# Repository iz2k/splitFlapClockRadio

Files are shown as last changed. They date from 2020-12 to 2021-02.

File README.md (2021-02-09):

# splitFlapClockRadio

---
**Table of contents**
- [DIY brief](#diy-brief)
- [3D design](#3d-design)
  * [SplitFlapDigit](#splitflapdigit)
  * [Cover](#cover)
- [Electronics hardware](#electronics-hardware)
- [SplitFlap controller firmware](#splitflap-controller-firmware)
- [Main Control Software](#main-control-software)
  * [Python backend](#python-backend)
  * [Angular Frontend](#angular-frontend)
    + [Dashboard](#dashboard)
    + [Clock](#clock)
    + [Radio](#radio)
    + [Spotify](#spotify)
    + [Sensors](#sensors)
    + [Weather](#weather)
    + [Historic](#historic)
---

The splitFlapClockRadio is an old stylish, classic alarm clock with up to date features, such as automatic time adjustment, weather forecast, air quality sensors, FM radio or Spotify playback. This is an updated version of the [Flip-Clock](https://github.com/iz2k/flip-clock), with slight modifications on the split-flap mechanics and integrated electronics. This device has been designed for DIY hobbists and can be manufactured for 100$ BOM.

| Outside | Inside |
|---|---|
||IMG_20210208_174947 - copia|

The splitFlapClockRadio features the following characteristics:
- Local time and weather on 3D printed split-flaps.
- 2W I2S Class-D Stereo Amplifier
- FM radio
- Spotify
- Air Quality measurements (eCO2 and TVOC)
- 32 x RGB LED array light
- Spoken weather forecasts (openWeatherMap + TTS)
- Volume and Media control rotary encoder wheels
- Powered by a Raspberry Pi 3A+

The project is divided in four main sections: 3D design, electronics hardware design, split-flap controller MCU firmware (C++) and main software (Python backend + Angular frontend).

## DIY brief
- [ ] Print 3D parts
- [ ] Manufacture PCB (<20$ with [JLCPB](https://jlcpcb.com/))
- [ ] Populate PCB with [Hot Air Gun](https://satkit.com/es/aoyue-int738-sistema-de-reparacion-profesional-soldador-60w)
- [ ] Flash MSP430 MCU
- [ ] Set-up fresh RaspberryPiOS Lite SD card ([tutorial](https://www.raspberrypi.org/software/))
- [ ] Install splitFlapClockRadio barebone:
`wget -O - https://raw.githubusercontent.com/iz2k/splitFlapClockRadio/master/sw/shInstall/barebone.sh | bash `
- [ ] Reboot and enjoy!

## 3D design

### SplitFlapDigit

Each split-flap digit consists of a support structure with two bearings. The axle is placed inside the bearings holding two flap holders. All the flaps are mounted within those holders. The movement of the digit is achieved with a stepper motor and two gears. A reflective IR sensor is used to detect falling flaps, and a hall sensor to synchronize the absolute position of the drum.


In order to get numbers and weather icons painted into the flaps, custom stencils have been designed and printed. The stencil design is avaiable at [iz2k/splitFlap-stencil](https://github.com/iz2k/splitFlap-stencil) repository.
stencil

### Cover
The cover consist on 3 main parts and 2 control wheels:
- Floor
- Top cover
- Frontal
- Volume wheel
- Media wheel


| Front Right |
|--------|
||

| Front Left |
|--------|
||

| Rear |
|--------|
||

## Electronics hardware
The electronics hardware integrates the following components:
- AC/DC converter
- MSP430FR2476 MCU as splitFlap controller
- 3 x ULN2003 stepper driver
- 3 x OPB733 reflective IR sensor
- 3 x DRV5055 hall sensor
- 1 x Si4731 FM radio tuner
- 2 x MAX98357 I2S audio amplifier (stereo)
- 32 x WS2812-2020 RGB LED
- Air Quality sensors: 1 x BME680 + 1 x SGP30/SGP40

splitFlapClockRadio_3D_Image
## SplitFlap controller firmware

The firmware runs on a MSP430 MCU and controls the driver of the three integrated stepper motors. The firmware keeps track of the falling flaps based on the reflected IR detector and synchronizes every cycle based on a hall efect sensor. The MCU can be commanded through I2C bus using SMBUS commands.

## Main Control Software
Tha main functionality of the clock is controlled by the Python backend. It controlls all the peripherals and makes the system work upon user interface with the rotary encoders or the orders triggered through the frontend.

The frontend is an Angular application that allows checking and modifying the current status and configuration of the system. It is accesible withtin the WLAN through a web browser ponting to the configured hostname of the Raspberry Pi.

### Python backend
The backend is divided in different packages to control specific peripherals of the systems:
- Alarm: controls activation of the configured alarms.
- Audio: controls the alsa sound system to trigger sounds and control volume.
- Clock: controls the split-flap controller via SMBUS.
- Config: controls the configuration file.
- DB: interfaces a MariaDB database to log periodic weather and Air Quality data.
- OsInfo: passes current OS infor to the frontend.
- RadioTuner: controls the integrated Si4731 FM tuner IC
- RgbStrip: controls the WS2812 RGB LED strip.
- SpotifyPlayer: activates raspotify device and controls the playback of spotify via spotify-cli.
- UserInterface: controls the Volume and Media rotary encoders.
- WeatherStation: gets weather information through OpenWeatherMap API and controls Air Quality sensors.
- WebServer: integrated Flask webserver to connect with the frontend via REST requests and/or websockets.

The backend is by default installed as a system service (autostart enabled), but can be stopped and launched manually to check its output.
``` bash
sudo service splitFlapClockRadioBackend stop
sudo splitFlapClockRadioBackend
```


### Angular Frontend
The frontend is also divided in different modules:
#### Dashboard
- Quik view of current status


#### Clock
- Current time and alarm list

- SplitFlap calibration

- Alarm configuration


#### Radio
- FM radio tuner control and stored station list.


#### Spotify
- Playback control and stored media item list

- Authentication

- Music search


#### Sensors
- Air Quality sensor data and calibration.


#### Weather
- Weather data, location configuration and API keys.


#### Historic
- Logged weather and Air Quality data


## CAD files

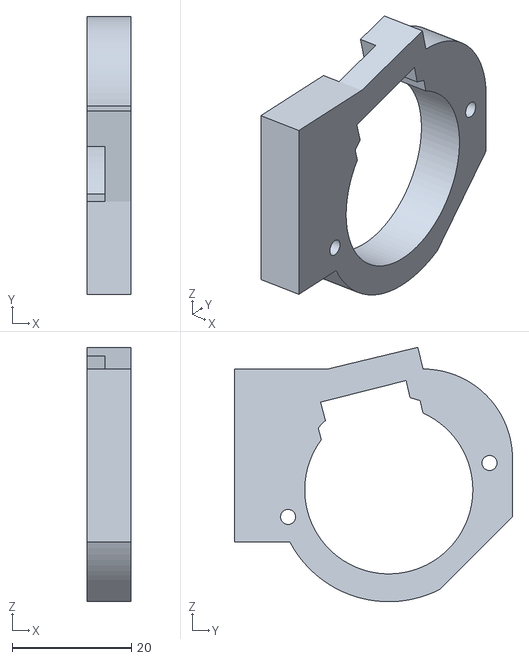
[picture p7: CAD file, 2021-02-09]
3d/outputs/support-stepper-R.stl
7.40 x 46.6 x 42.7

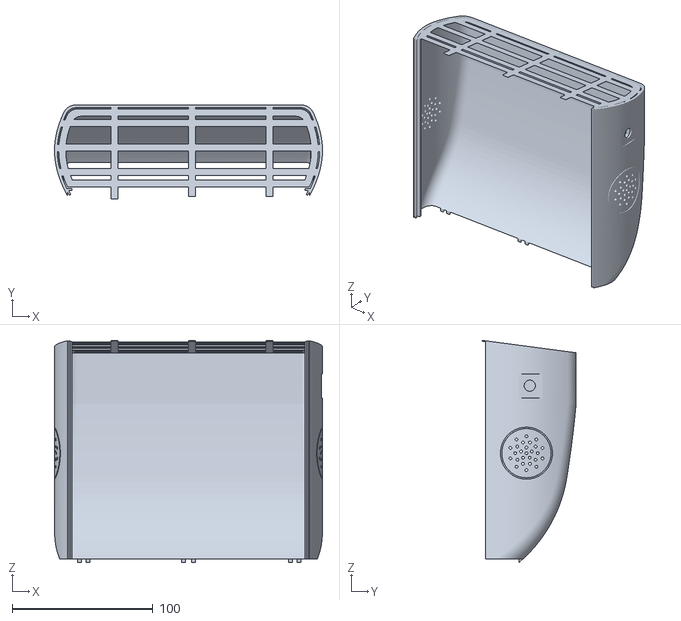
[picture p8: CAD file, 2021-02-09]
3d/outputs/cover.stl
190.6 x 67.1 x 158.1

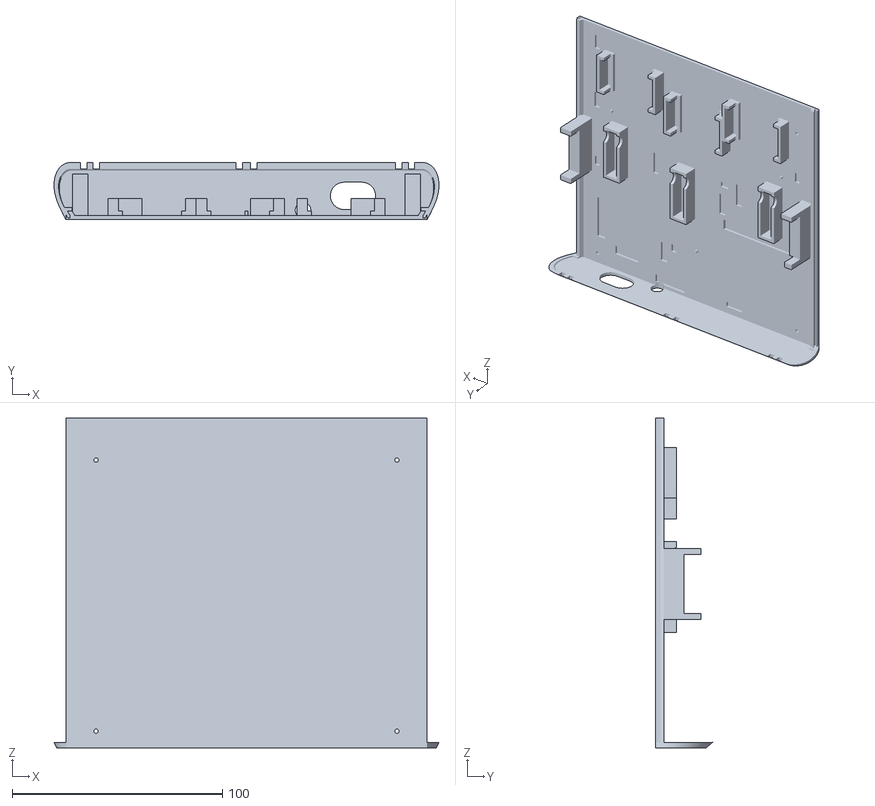
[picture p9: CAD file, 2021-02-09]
3d/outputs/floor.stl
183.2 x 27.1 x 157.0

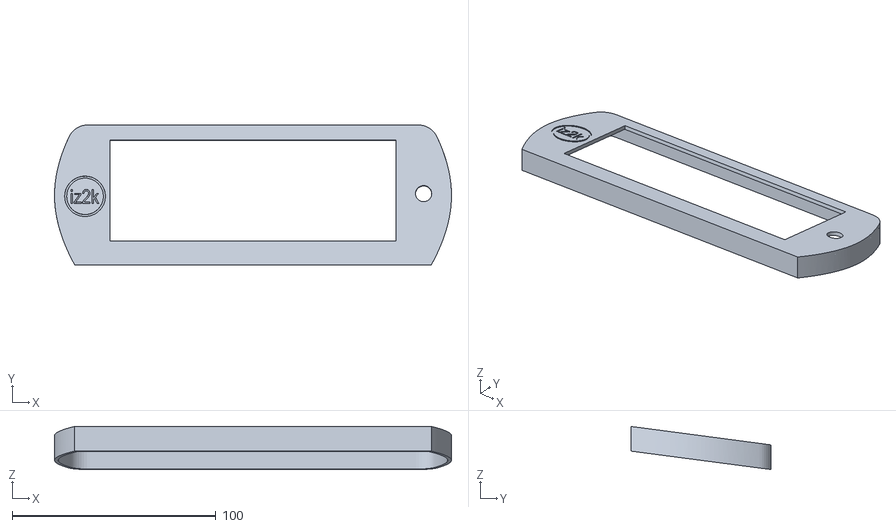
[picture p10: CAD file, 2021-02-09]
3d/outputs/Frontal.stl
194.6 x 68.6 x 21.1

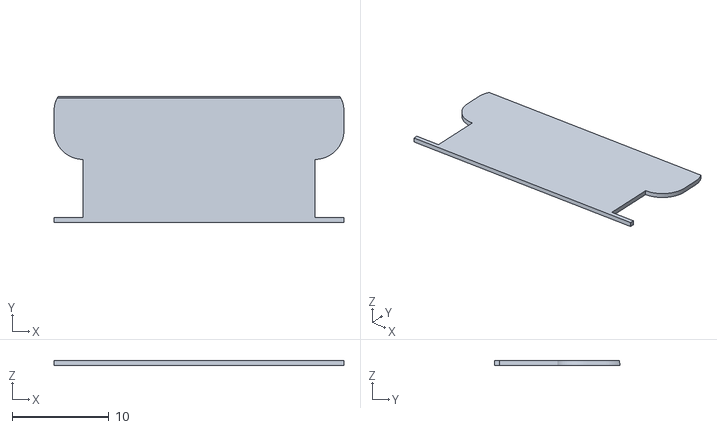
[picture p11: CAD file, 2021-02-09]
3d/outputs/flap-60.stl
30.0 x 13.0 x 0.5

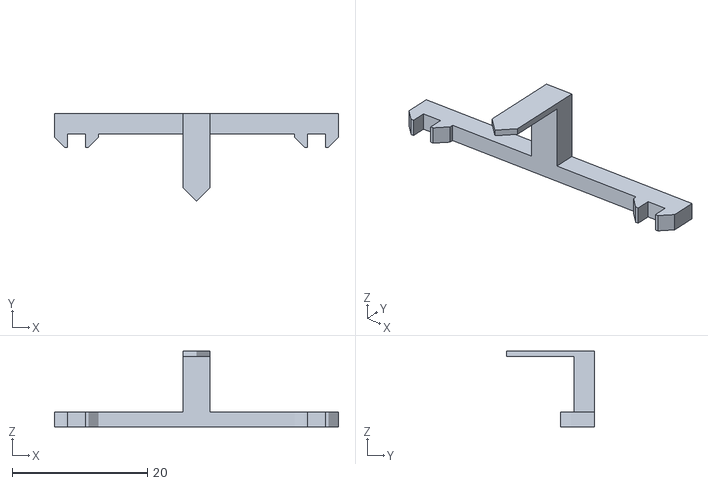
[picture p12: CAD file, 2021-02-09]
3d/outputs/support-drum-bridge-60.stl
42.0 x 13.0 x 11.2

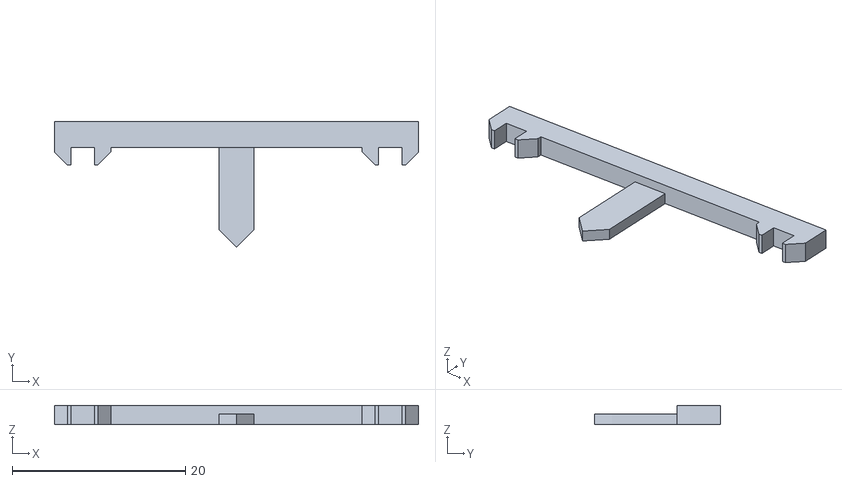
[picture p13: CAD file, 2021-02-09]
3d/outputs/support-drum-bridge-24.stl
42.0 x 14.5 x 2.20

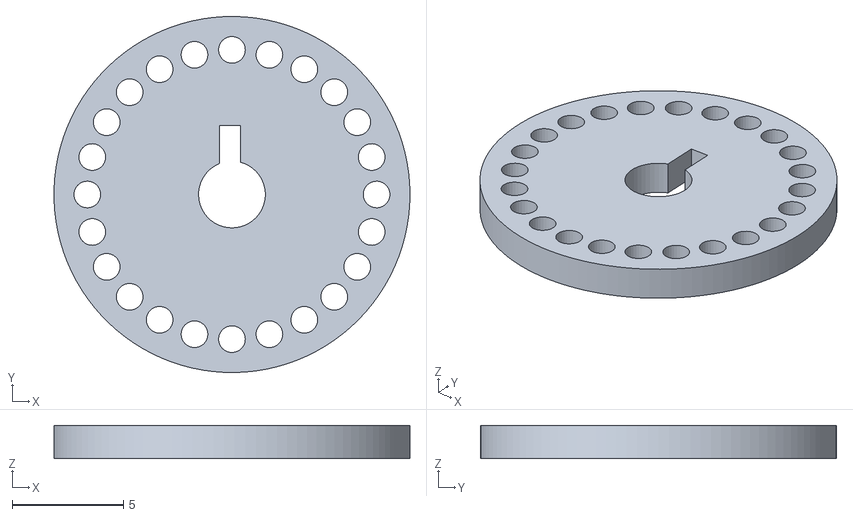
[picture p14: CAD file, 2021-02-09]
3d/outputs/flap-holder-24.stl
16.0 x 16.0 x 1.50

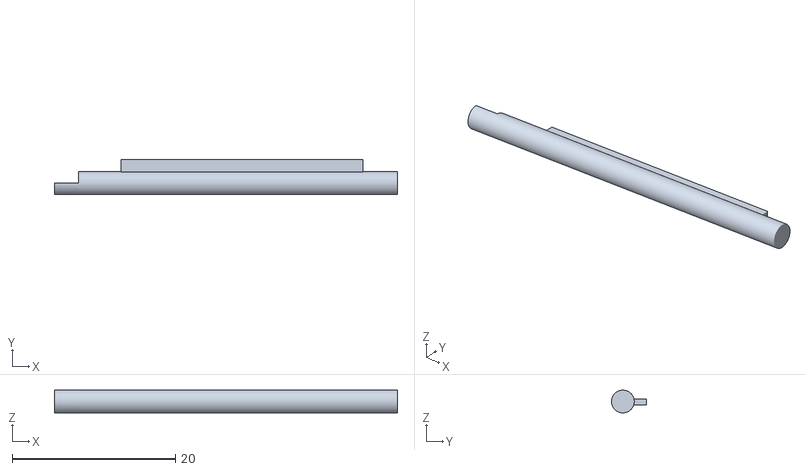
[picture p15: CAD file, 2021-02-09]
3d/outputs/axle.stl
42.0 x 4.30 x 2.80

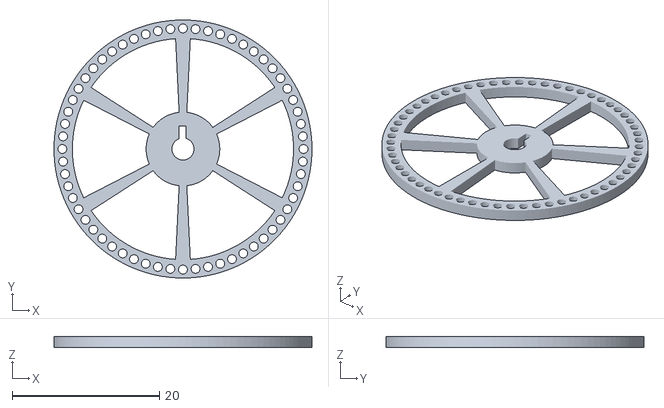
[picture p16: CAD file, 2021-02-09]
3d/outputs/flap-holder-60.stl
35.0 x 35.0 x 1.50

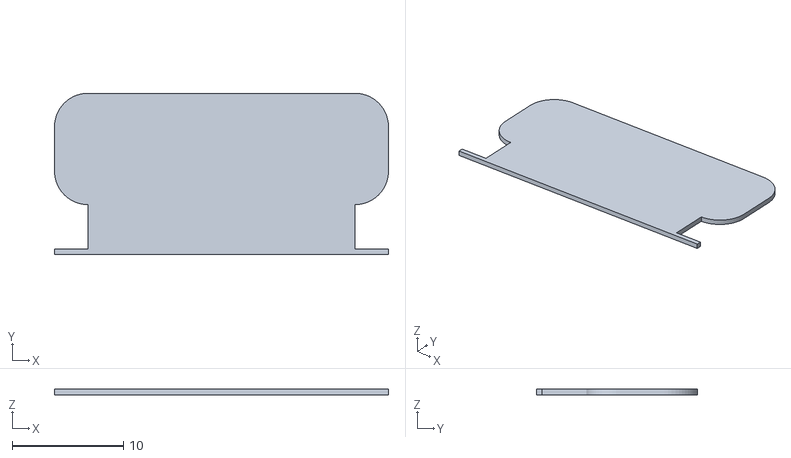
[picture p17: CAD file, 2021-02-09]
3d/outputs/flap-24.stl
30.0 x 14.5 x 0.5

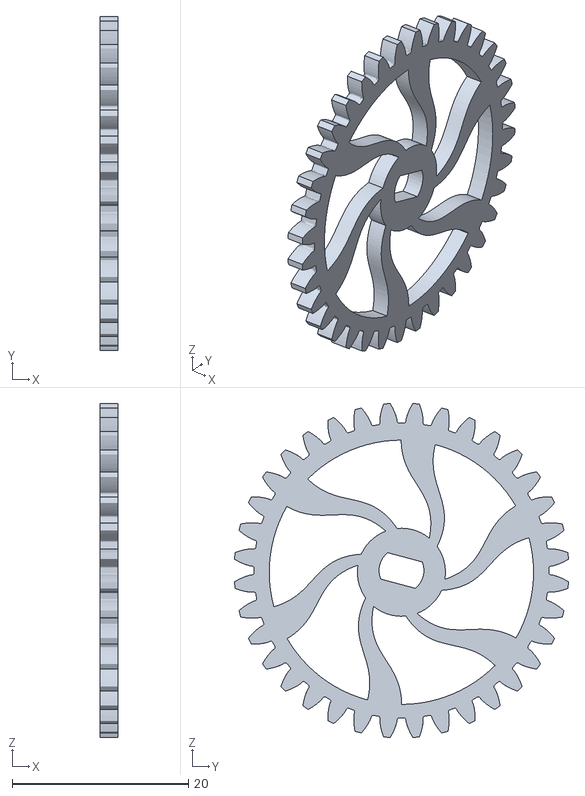
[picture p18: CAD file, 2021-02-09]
3d/outputs/gear-stepper.stl
2.00 x 37.9 x 37.9

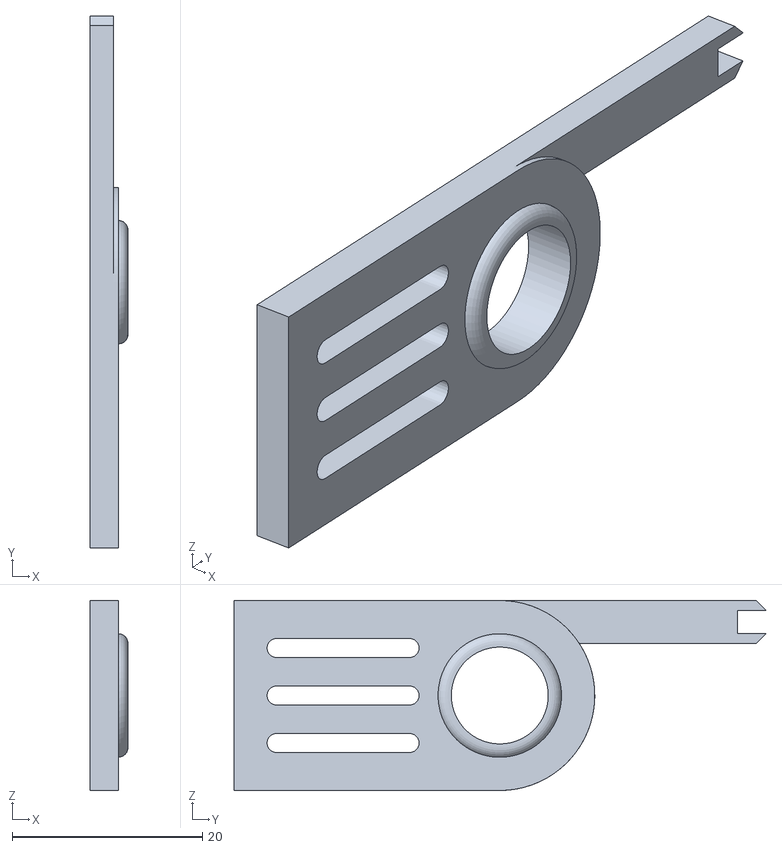
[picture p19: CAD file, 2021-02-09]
3d/outputs/support-drum-L.stl
4.00 x 56.0 x 20.0

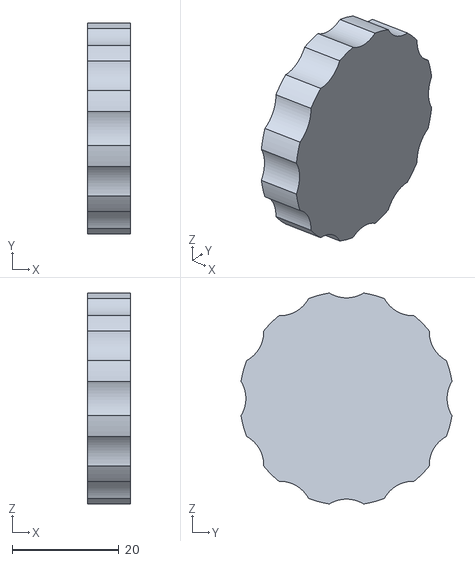
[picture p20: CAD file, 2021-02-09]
3d/outputs/ui_Volume_Wheel.stl
8.00 x 39.5 x 39.5

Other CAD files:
3d/outputs/support-stepper-L.stl
3d/outputs/ui_Control_Wheel.stl
3d/outputs/support-drum-R.stl
3d/outputs/footer.stl
3d/outputs/gear-axle.stl

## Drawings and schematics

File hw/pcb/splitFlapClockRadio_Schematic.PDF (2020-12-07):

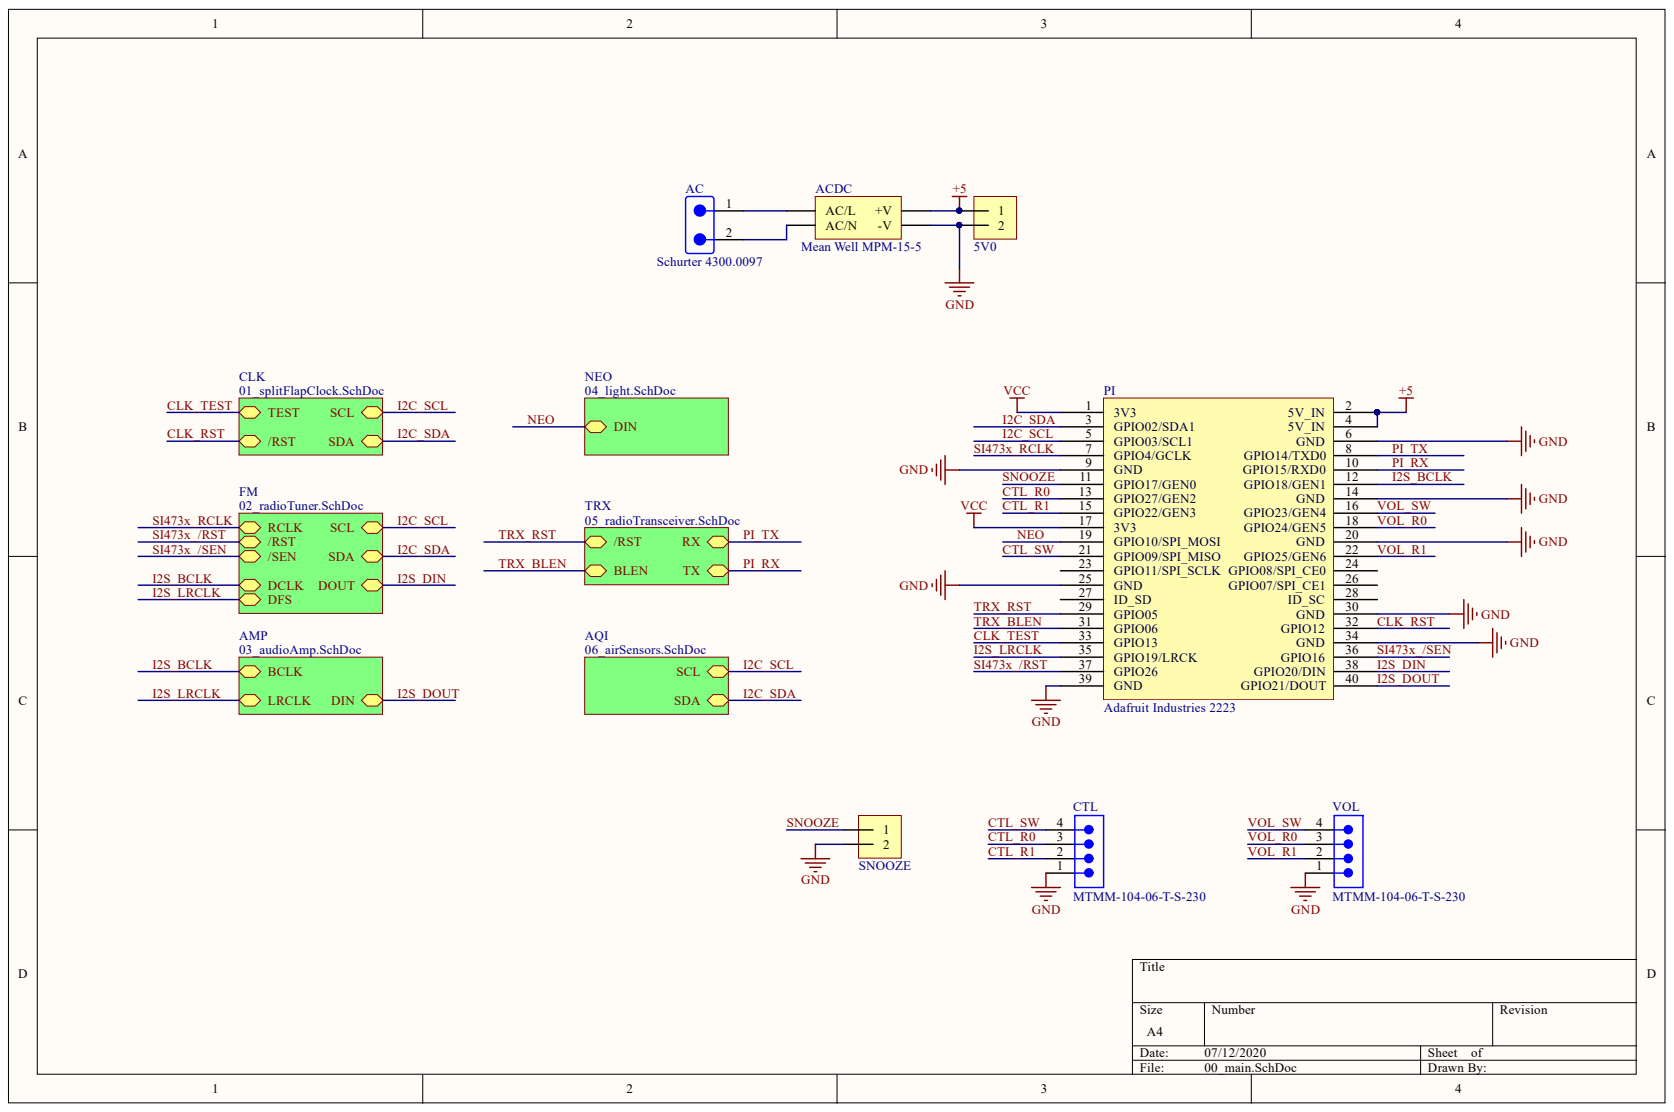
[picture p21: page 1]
Date:; Sheet of; File:; 00_main.SchDoc; Drawn By:; 4 GPIO02/SDA1 3; GPIO03/SCL1 5; GND; GPIO4/GCLK 7; GPIO14/TXD0; GND 9; GPIO15/RXD0; GPIO17/GEN0 11 GPIO27/GEN2 13 GPIO22/GEN3 15 3V3 17 GPIO10/SPI_MOSI 19 GPIO09/SPI_MISO 21 GPIO11/SPI_SCLK 23 GND 25; GPIO05 29 GPIO06 31 GPIO13 33 GPIO19/LRCK 35 GPIO26 37; GND 39; GPIO21/DOUT; 40 GPIO20/DIN; 38 GPIO16; 36 GND; 34 GPIO12; 32 GND; GPIO07/SPI_CE1; 26 GPIO08/SPI_CE0; 24 GPIO25/GEN6; 22 GND; 20 GPIO24/GEN5; 18 GPIO23/GEN4; 16 GND; 14 GPIO18/GEN1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

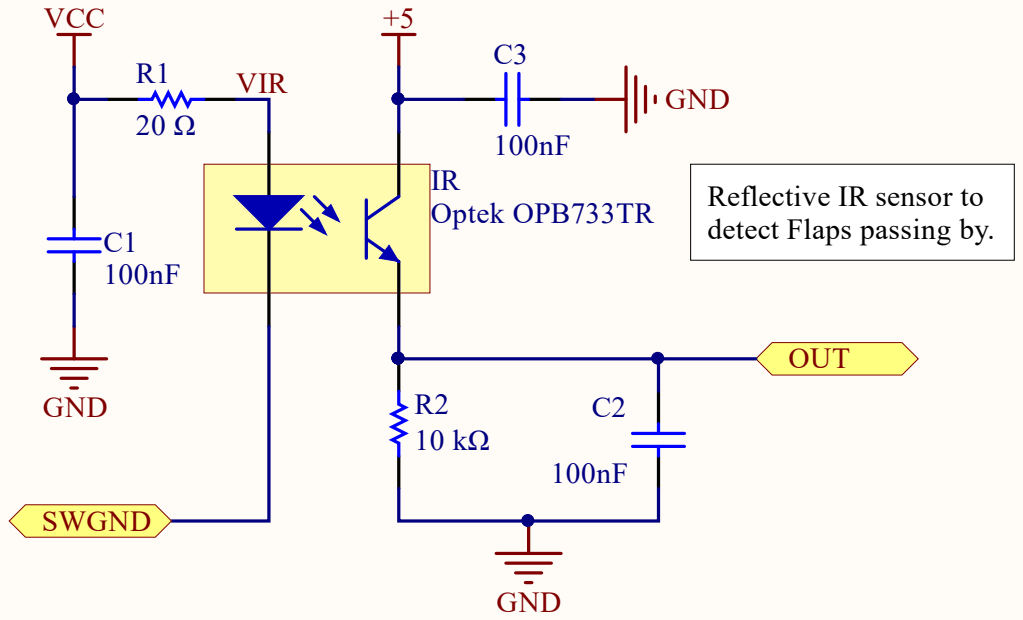
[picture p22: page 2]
File:; 01_a_splitFlapDetector.SchDoc; Drawn By:; Optek OPB733TR

Reflective IR sensor to
detect Flaps passing by.

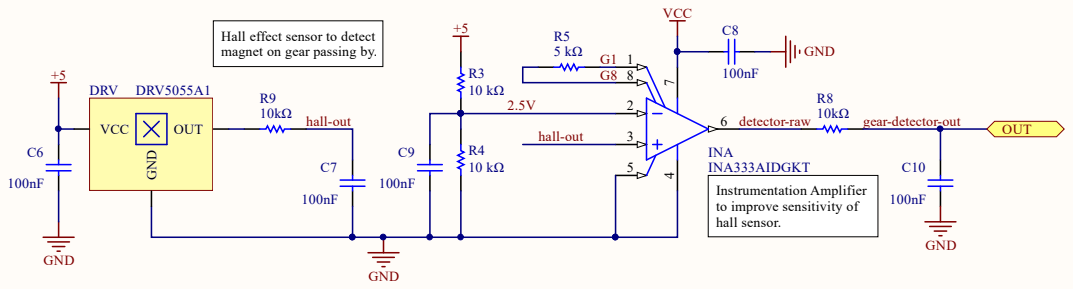
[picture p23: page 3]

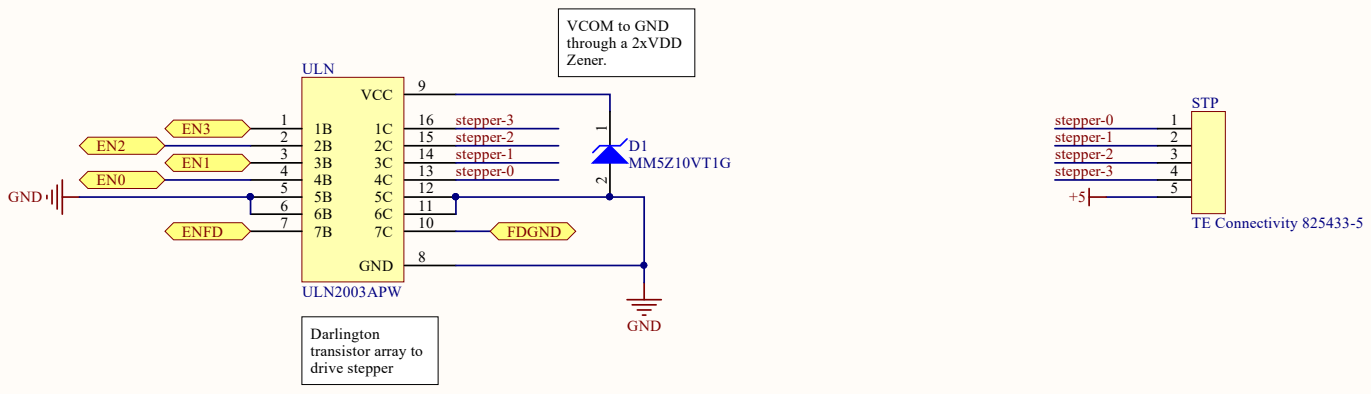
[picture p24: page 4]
Sheet o; or array t; VCOM t; PID102 COD1; PID102 PIULN05; PID101 PIULN09; NLstepper03 POEN0POEN1

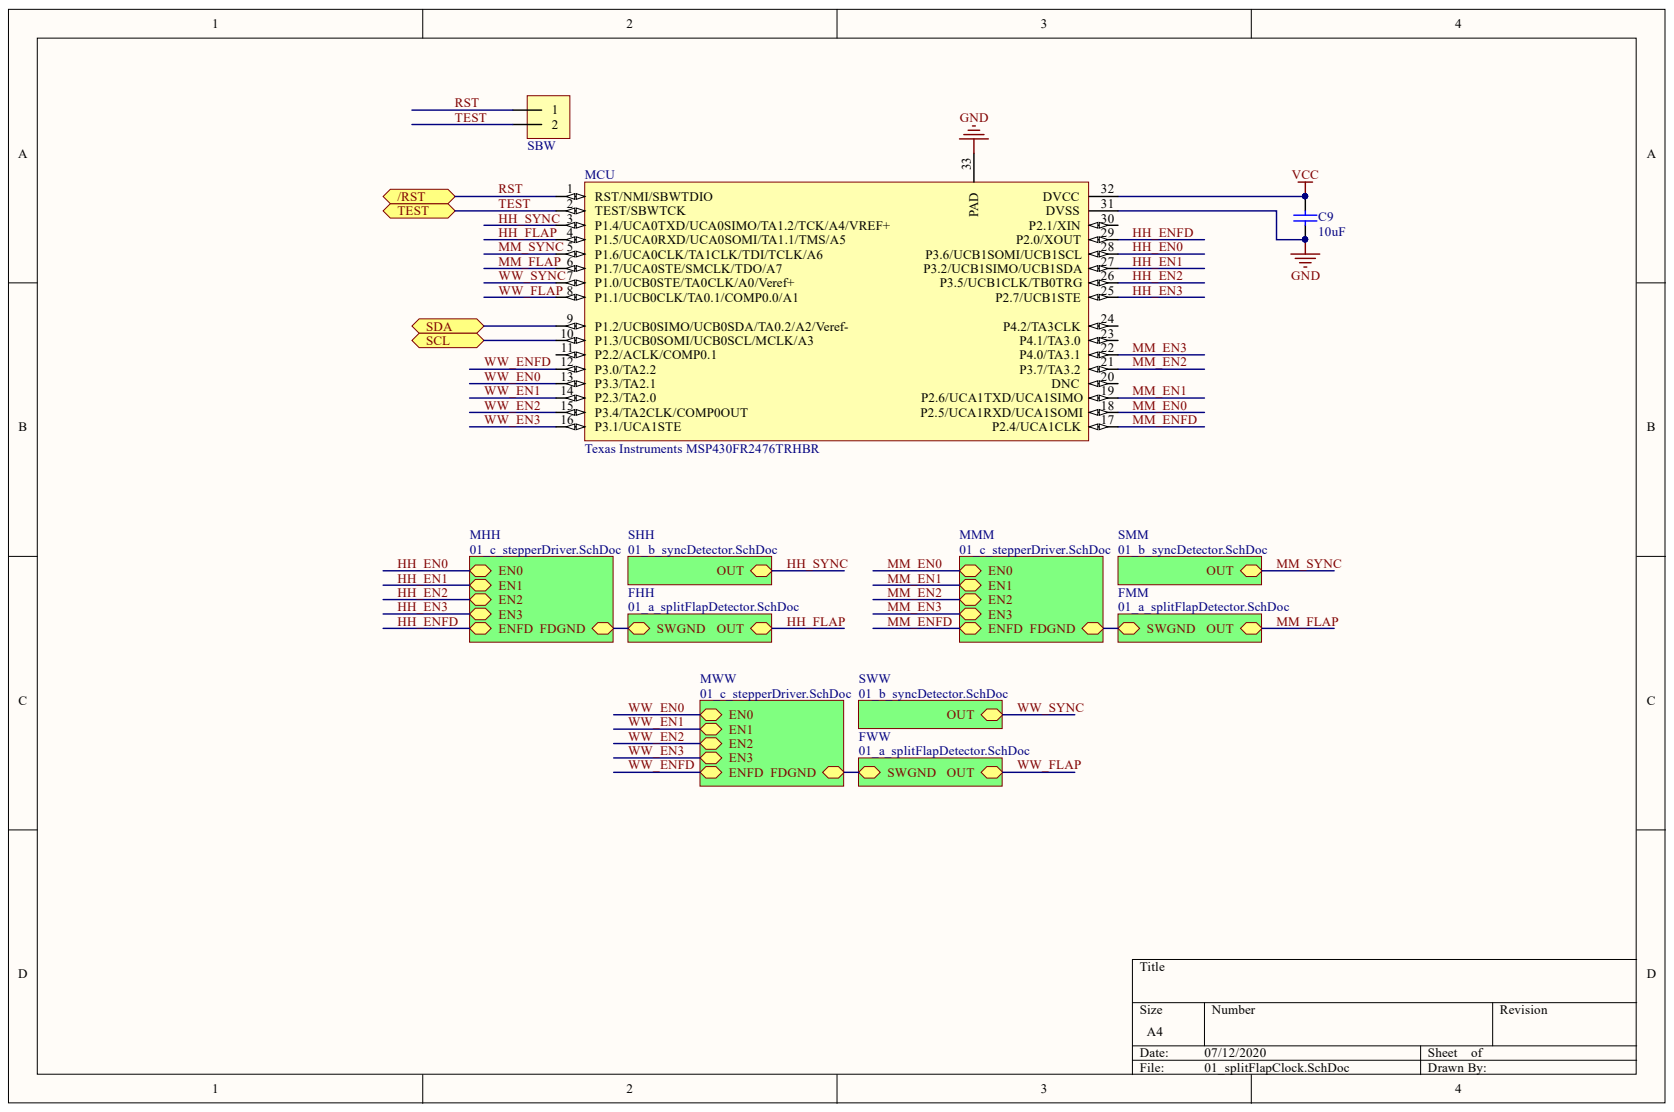
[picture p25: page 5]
File:; 01_splitFlapClock.SchDoc; Drawn By:; SWGND OUT; HH_FLAP; RST/NMI/SBWTDIO 1 TEST/SBWTCK 2 P1.4/UCA0TXD/UCA0SIMO/TA1.2/TCK/A4/VREF+ 3 P1.5/UCA0RXD/UCA0SOMI/TA1.1/TMS/A5 4 P1.6/UCA0CLK/TA1CLK/TDI/TCLK/A6 5 P1.7/UCA0STE/SMCLK/TDO/A7 6 P1.0/UCB0STE/TA0CLK/A0/Veref+ 7 P1.1/UCB0CLK/TA0.1/COMP0.0/A1 8; P1.2/UCB0SIMO/UCB0SDA/TA0.2/A2/Veref- 9 P1.3/UCB0SOMI/UCB0SCL/MCLK/A3 10 P2.2/ACLK/COMP0.1 11 P3.0/TA2.2 12 P3.3/TA2.1 13 P2.3/TA2.0 14 P3.4/TA2CLK/COMP0OUT 15 P3.1/UCA1STE 16; P2.7/UCB1STE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

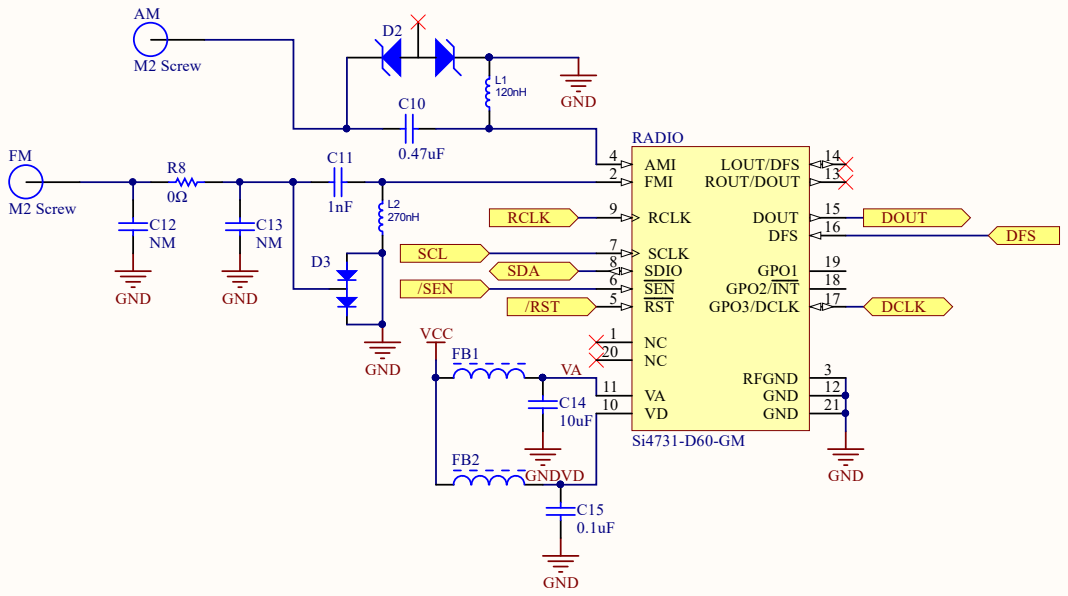
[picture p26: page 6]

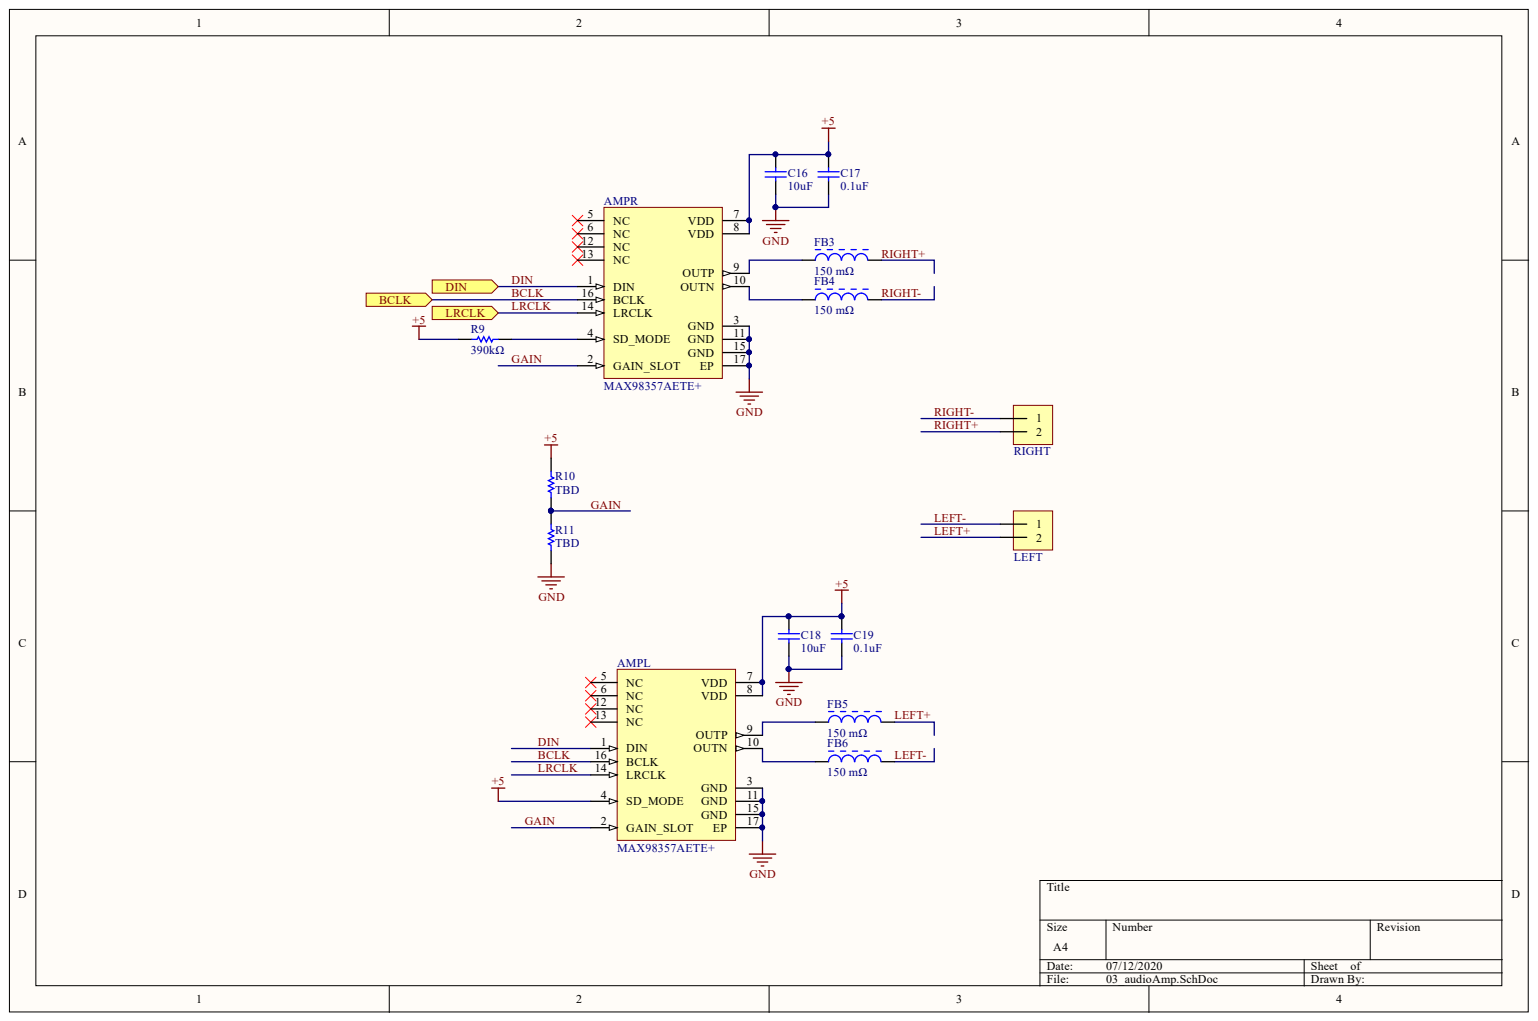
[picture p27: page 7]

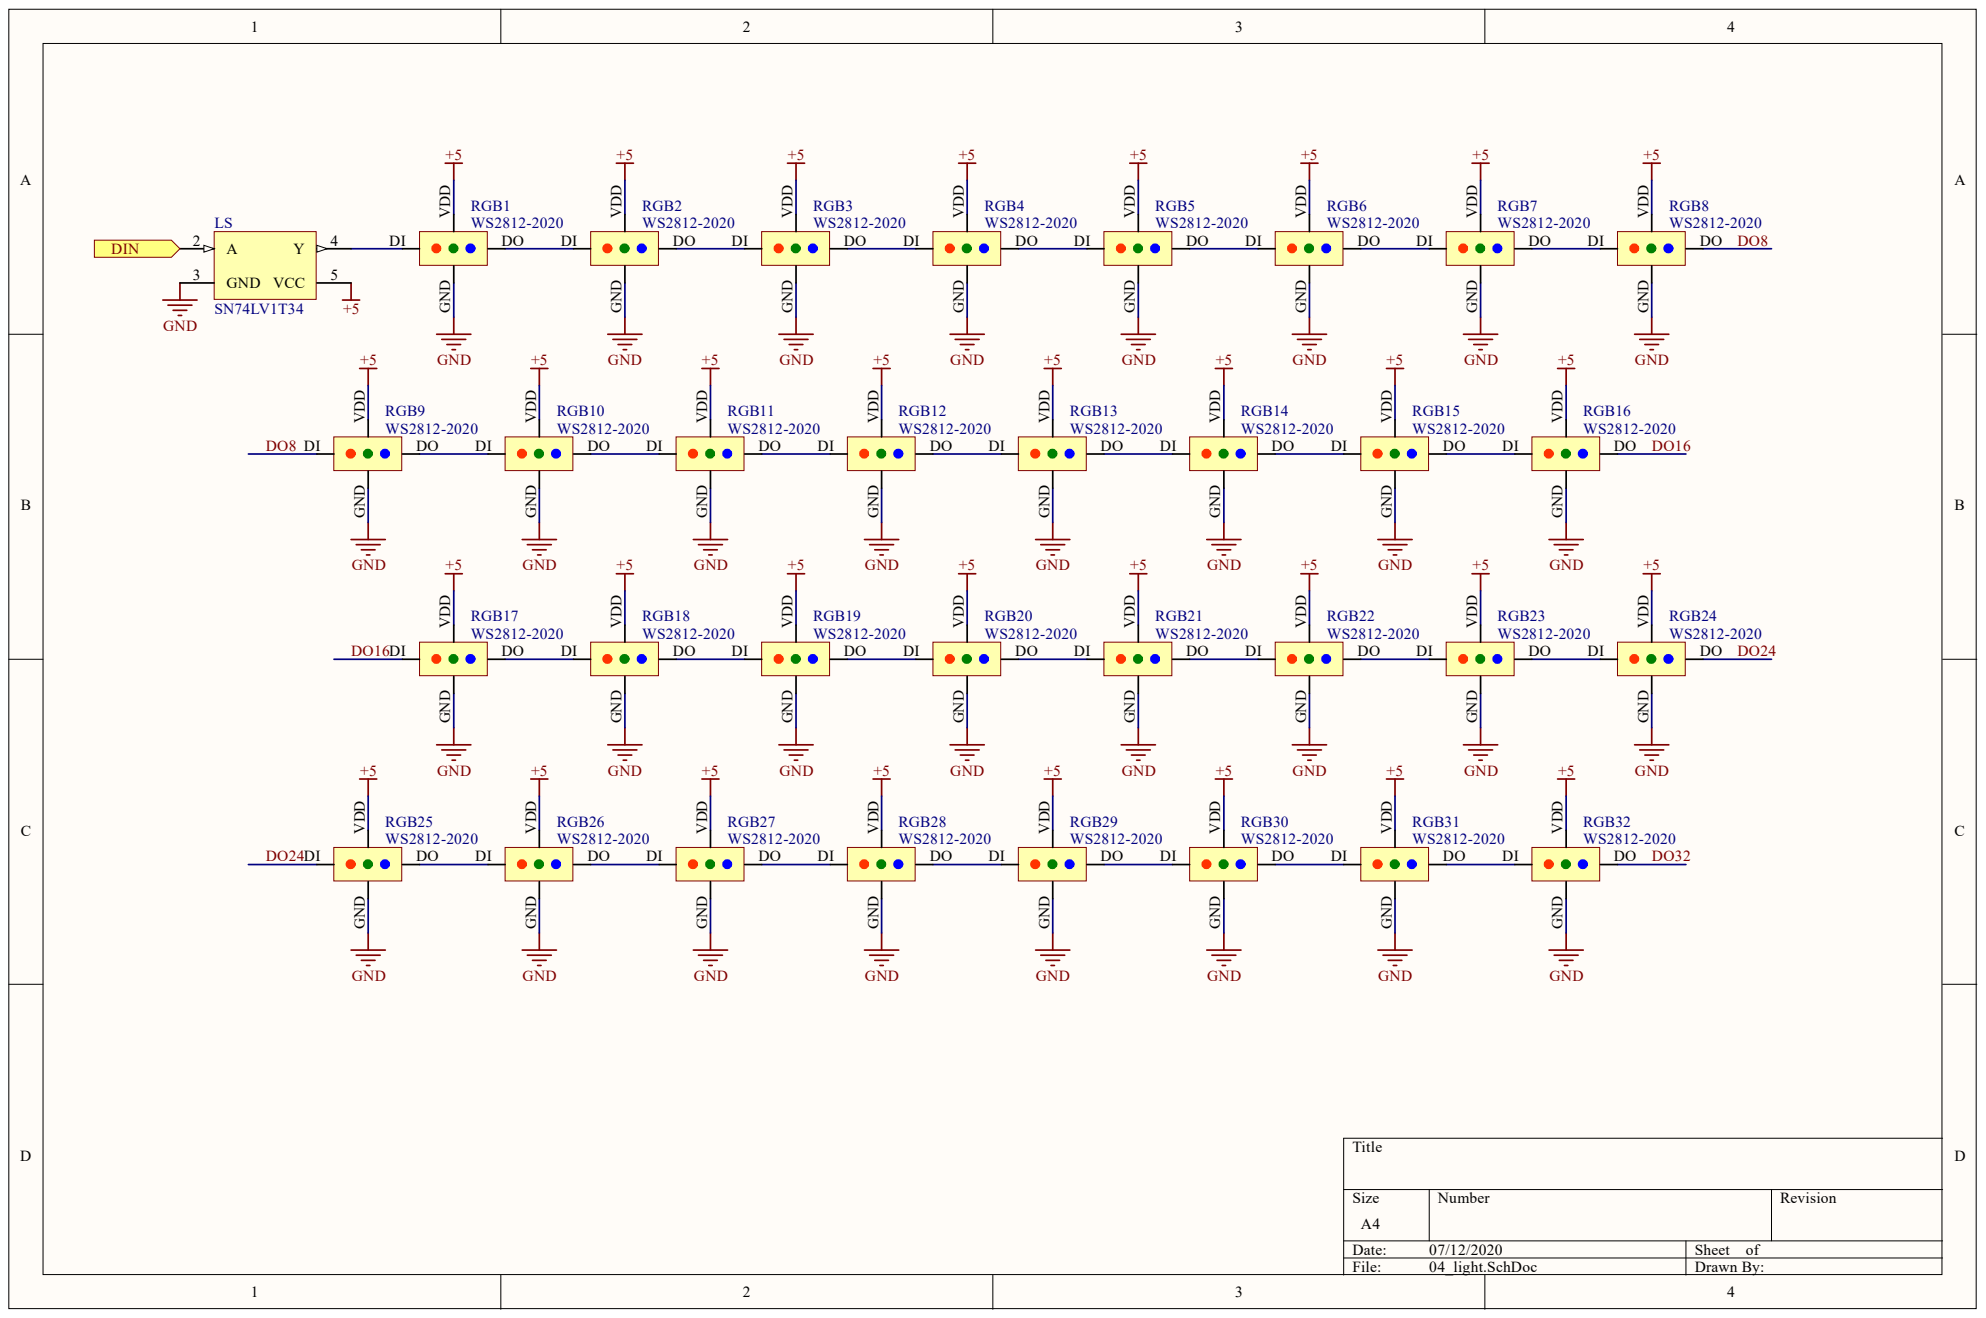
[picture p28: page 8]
File:; 04_light.SchDoc; Drawn By:; GND 3; PIRGB50VDD CORGB5; PIRGB60VDD CORGB6; PIRGB70VDD CORGB7; PIRGB80VDD CORGB8; PIRGB90VDD CORGB9; PIRGB140VDD CORGB14; PIRGB150VDD CORGB15; PIRGB160VDD CORGB16; PIRGB210VDD CORGB21; PIRGB220VDD CORGB22; PIRGB230VDD CORGB23; PIRGB240VDD CORGB24; PIRGB300VDD CORGB30; PIRGB310VDD CORGB31; PIRGB320VDD CORGB32

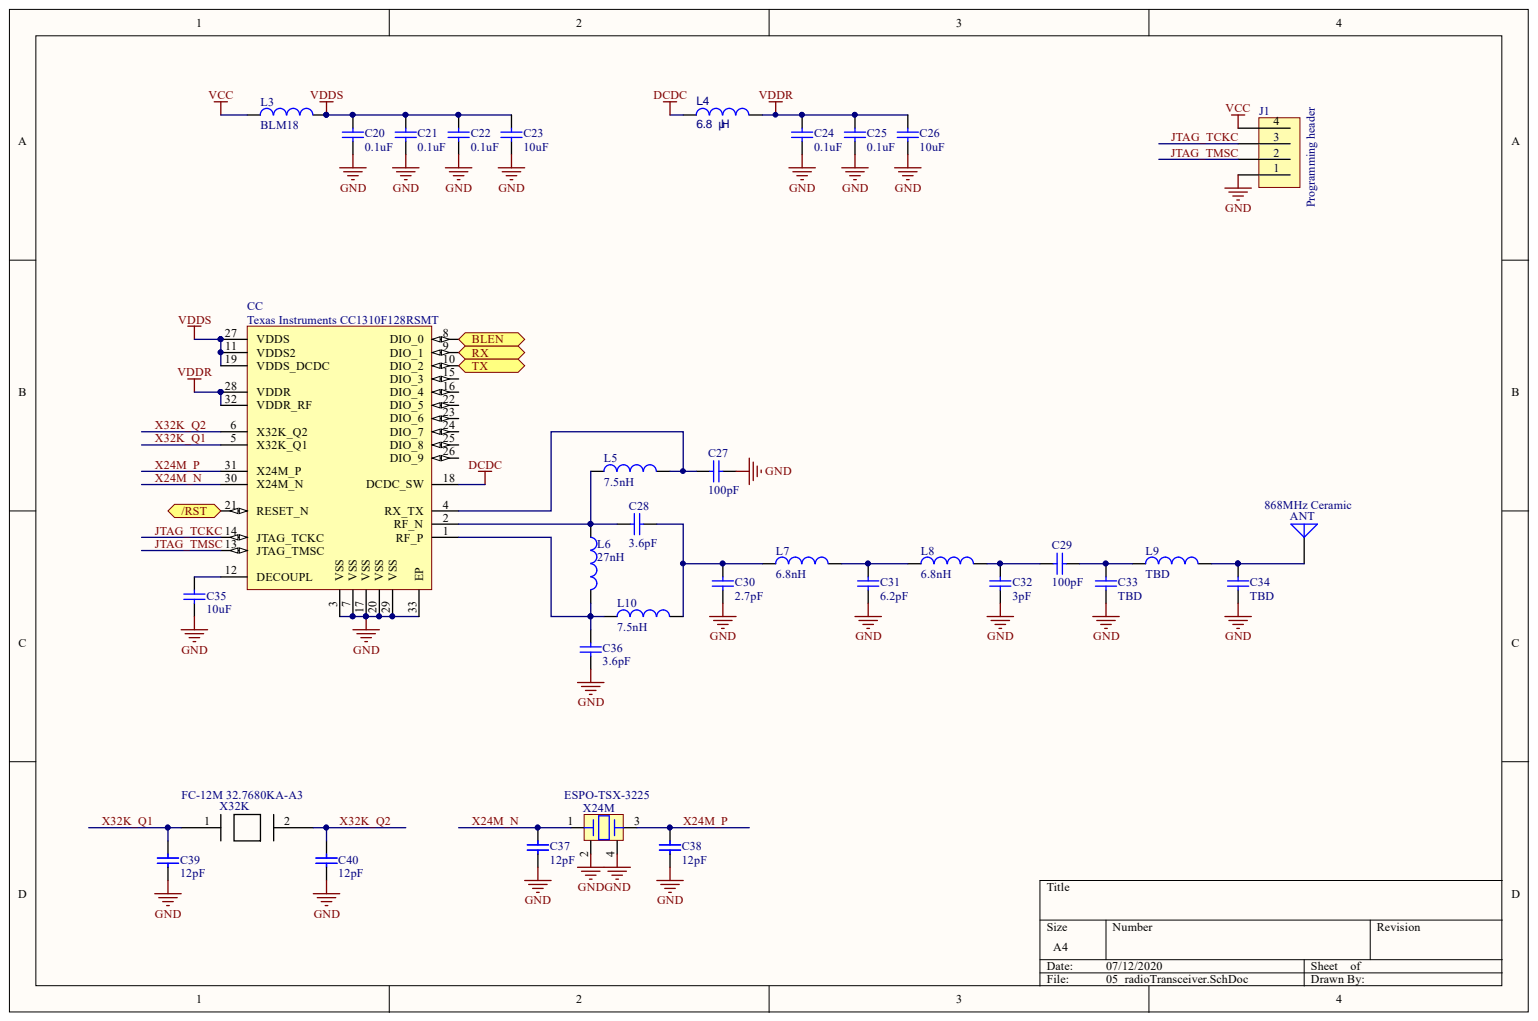
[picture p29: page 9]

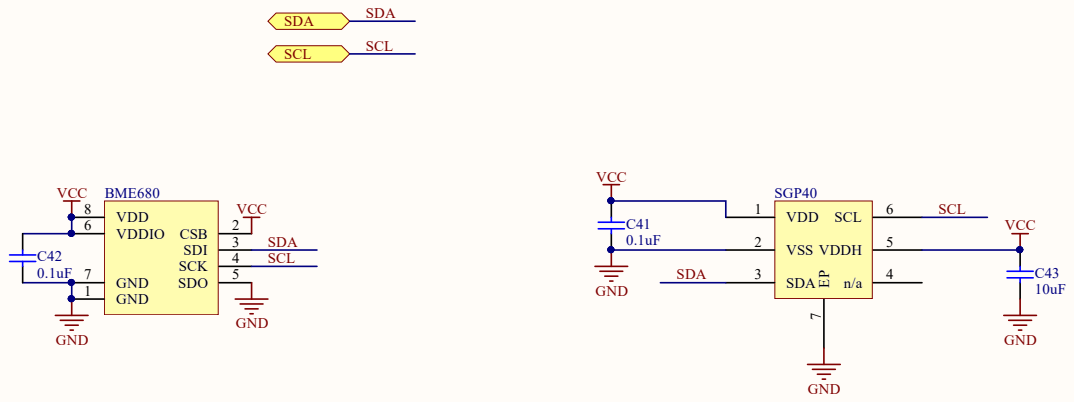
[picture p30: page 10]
File:; 06_airSensors.SchDoc; Drawn By:; GND 1; VDD 8; GND 7; VDDIO 6; VDD 1; VSS 2; SDA 3

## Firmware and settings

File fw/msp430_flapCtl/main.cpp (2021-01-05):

#include <msp430.h>
#include <board.h>
#include <system/cs.h>
#include <system/sysTimer.h>
#include <adc/Adc.h>
#include <smbus/smbusSlave.h>
#include <splitFlap/SplitFlap.h>


void defineSmbusRegisterMap(SplitFlap*, SplitFlap*, SplitFlap*);
extern bool flagSysTimer;

int main(void)
{
    // Stop WDT
    WDTCTL = WDTPW | WDTHOLD;

    // Initialize system
    initCS();
    initSysTimer();

    // Create ADC controller
    Adc adc = Adc();

    // Create stepper objects
    SplitFlap hhSplitFlap = SplitFlap(&hhSplitFlapDef, &adc);
    SplitFlap mmSplitFlap = SplitFlap(&mmSplitFlapDef, &adc);
    SplitFlap wwSplitFlap = SplitFlap(&wwSplitFlapDef, &adc);

    // Register SMBUS map
    defineSmbusRegisterMap(&hhSplitFlap, &mmSplitFlap, &wwSplitFlap);

    // Initialize SMBus slave
    initSmbusSlave();

    // Disable High-Z GPIOs
    PM5CTL0 &= ~LOCKLPM5;

    // Enable Global Interrupts
    __bis_SR_register(GIE);

    // Endless loop
    while(true)
    {
        // Check sysTimer event
        if(flagSysTimer == true){
            // Deassert flag
            flagSysTimer = false;

            // Run steppers
            hhSplitFlap.run();
            mmSplitFlap.run();
            wwSplitFlap.run();
        }

    }

}

void defineSmbusRegisterMap(SplitFlap *sfHH, SplitFlap *sfMM, SplitFlap *sfWW)
{
    /* FW VERSION */
    addSmbusRegister({
        .smbusAddress=0,
        .mcuAddress=(void*) &fw_version,
        .length=2});

    /* HH */
    addSmbusRegister({
        .smbusAddress=1,
        .mcuAddress=(void*) &hh_ir_threshold,
        .length=2});

    addSmbusRegister({
        .smbusAddress=2,
        .mcuAddress=(void*) &hh_hall_threshold,
        .length=2});

    addSmbusRegister({
        .smbusAddress=3,
        .mcuAddress=(void*) &hh_hall_digit,
        .length=1});

    addSmbusRegister({
        .smbusAddress=4,
        .mcuAddress=(void*) &(*sfHH).currentDigit,
        .length=1});

    addSmbusRegister({
        .smbusAddress=5,
        .mcuAddress=(void*) &(*sfHH).desiredDigit,
        .length=1});

    addSmbusRegister({
        .smbusAddress=6,
        .mcuAddress=(void*) &(*sfHH).currentIR,
        .length=2});

    addSmbusRegister({
        .smbusAddress=7,
        .mcuAddress=(void*) &(*sfHH).currentHall,
        .length=2});

    addSmbusRegister({
        .smbusAddress=8,
        .mcuAddress=(void*) &(*sfHH).syncTrigger,
        .length=1});


    addSmbusRegister({
        .smbusAddress=9,
        .mcuAddress=(void*) &hh_debounce,
        .length=2});


    /* MM */
    addSmbusRegister({
        .smbusAddress=11,
        .mcuAddress=(void*) &mm_ir_threshold,
        .length=2});

    addSmbusRegister({
        .smbusAddress=12,
        .mcuAddress=(void*) &mm_hall_threshold,
        .length=2});

    addSmbusRegister({
        .smbusAddress=13,
        .mcuAddress=(void*) &mm_hall_digit,
        .length=1});

    addSmbusRegister({
        .smbusAddress=14,
        .mcuAddress=(void*) &(*sfMM).currentDigit,
        .length=1});

    addSmbusRegister({
        .smbusAddress=15,
        .mcuAddress=(void*) &(*sfMM).desiredDigit,
        .length=1});

    addSmbusRegister({
        .smbusAddress=16,
        .mcuAddress=(void*) &(*sfMM).currentIR,
        .length=2});

    addSmbusRegister({
        .smbusAddress=17,
        .mcuAddress=(void*) &(*sfMM).currentHall,
        .length=2});

    addSmbusRegister({
        .smbusAddress=18,
        .mcuAddress=(void*) &(*sfMM).syncTrigger,
        .length=1});

    addSmbusRegister({
        .smbusAddress=19,
        .mcuAddress=(void*) &mm_debounce,
        .length=2});


    /* WW */
    addSmbusRegister({
        .smbusAddress=21,
        .mcuAddress=(void*) &ww_ir_threshold,
        .length=2});

    addSmbusRegister({
        .smbusAddress=22,
        .mcuAddress=(void*) &ww_hall_threshold,
        .length=2});

    addSmbusRegister({
        .smbusAddress=23,
        .mcuAddress=(void*) &ww_hall_digit,
        .length=1});

    addSmbusRegister({
        .smbusAddress=24,
        .mcuAddress=(void*) &(*sfWW).currentDigit,
        .length=1});

    addSmbusRegister({
        .smbusAddress=25,
        .mcuAddress=(void*) &(*sfWW).desiredDigit,
        .length=1});

    addSmbusRegister({
        .smbusAddress=26,
        .mcuAddress=(void*) &(*sfWW).currentIR,
        .length=2});

    addSmbusRegister({
        .smbusAddress=27,
        .mcuAddress=(void*) &(*sfWW).currentHall,
        .length=2});

    addSmbusRegister({
        .smbusAddress=28,
        .mcuAddress=(void*) &(*sfWW).syncTrigger,
        .length=1});

    addSmbusRegister({
        .smbusAddress=29,
        .mcuAddress=(void*) &ww_debounce,
        .length=2});

}

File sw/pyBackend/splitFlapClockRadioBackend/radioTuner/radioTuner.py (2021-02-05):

import time
from datetime import timedelta
from queue import Queue
from threading import Thread

from splitFlapClockRadioBackend.radioTuner.si4731 import Si4731
from splitFlapClockRadioBackend.tools.jsonTools import prettyJson
from splitFlapClockRadioBackend.tools.osTools import start_service
from splitFlapClockRadioBackend.tools.timeTools import getNow


class RadioTuner(Thread):

    queue = Queue()
    radioTuner = None
    lastReport = None
    freq = None

    def __init__(self, app):
        Thread.__init__(self)
        from splitFlapClockRadioBackend.__main__ import App
        self.app: App = app
        self.radioTuner = Si4731()
        start_service('i2s-pipe')
        self.lastReport = self.radioTuner.get_info_obj()

        from splitFlapClockRadioBackend.radioTuner.radioTunerWebRoutes import defineRadioTunerWebRoutes
        defineRadioTunerWebRoutes(self.app)

        self.start()

    def start(self):
        Thread.start(self)

    def stop(self):
        if self.is_alive():
            self.queue.put(['quit', 0])
            self.join()
            print('RadioTuner thread exit.')

    def run(self):

        interval_seconds = 0.5

        last_update = getNow() - timedelta(seconds=interval_seconds)
        # Main loop
        run_app=True
        while(run_app):

            # Update Radio Signal Quality
            self.radioTuner.get_rsq_status()

            # Check if RDS data vailable
            if (self.radioTuner.check_rds()):
                # Get and Process RDS data
                self.radioTuner.get_rds_status()

            # Check if msg in queue
            while not self.queue.empty():
                [q_msg, q_data] = self.queue.get()
                if q_msg == 'quit':
                    run_app=False
                if (q_msg == 'reset'):
                    self.radioTuner.__init__()
                    if self.freq != None:
                        self.radioTuner.fm_tune(self.freq)
                if (q_msg == 'tune'):
                    self.radioTuner.fm_tune(q_data)
                if (q_msg == 'turn_on'):
                    self.radioTuner.turn(True)
                if (q_msg == 'turn_off'):
                    self.radioTuner.turn(False)
                    self.emitFmRadioReport()
                if (q_msg == 'seek_up'):
                    self.radioTuner.fm_seek_up()
                if (q_msg == 'seek_down'):
                    self.radioTuner.fm_seek_down()

            if self.detectFmRadioReportChange():
                if self.radioTuner.on:
                    self.emitFmRadioReport()

            time.sleep(0.1)


    def tune(self, freq):
        self.freq = freq
        self.queue.put(['tune', self.freq])
        print('[radio] TUNE ' + str(self.freq) + 'MHz')

    def play(self):
        self.queue.put(['reset', 0])
        self.queue.put(['turn_on', 0])
        print('[radio] PLAY')

    def pause(self):
        self.queue.put(['turn_off', 0])
        print('[radio] PAUSE')


    def next(self):
        self.queue.put(['seek_up', 0])
        print('[radio] SEEK UP')


    def previous(self):
        self.queue.put(['seek_down', 0])
        print('[radio] SEEK DOWN')

    def detectFmRadioReportChange(self):
        newReport = self.radioTuner.get_info_obj()
        hasChanged = False
        for key in self.lastReport:
            if (self.lastReport[key] != newReport[key]):
                hasChanged = True
        self.lastReport = newReport
        return hasChanged

    def emitFmRadioReport(self):
        self.app.webserver.sio.emit('fmRadioReport', prettyJson(self.radioTuner.get_info_obj()))

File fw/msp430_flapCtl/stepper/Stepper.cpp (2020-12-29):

#include <stepper/Stepper.h>

Stepper::Stepper() {
};

Stepper::Stepper(const StepperDef *stepperDef) {
    for(int i=3; i>=0; i--){
        this->gpo[i] = Gpo(&stepperDef->gpoDefs[i]);
    }
    this->direction = stepperDef->direction;
    this->divisor = stepperDef->divisor;
    this->idxDiv=0;
    this->idxStep=0;
};

const uint8_t stepMatrix [8][4] =
{
  {1, 0, 0, 0},
  {1, 1, 0, 0},
  {0, 1, 0, 0},
  {0, 1, 1, 0},
  {0, 0, 1, 0},
  {0, 0, 1, 1},
  {0, 0, 0, 1},
  {1, 0, 0, 1}
};
void Stepper::move() {
    if(++this->idxDiv==this->divisor){
        this->idxDiv=0;
        for(int i=3; i>=0; i--){
            stepMatrix[this->idxStep][i] ? (this->gpo[i].set()) : (this->gpo[i].clear());
        }

        if(this->direction == ClockWise)
        {
            if(--this->idxStep>7)this->idxStep=7;
        }else{
            if(++this->idxStep>7)this->idxStep=0;
        }
    }
};

void Stepper::stop() {
    for(int i=3; i>=0; i--){
        this->gpo[i].clear();
    }
    this->idxStep=0;
};

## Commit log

2020-12-07 1V0 HW PCB outputs included.
2020-12-11 fw squeleton with stepper gpio test
2020-12-20 working on rotary encoder... something is failing... maybe hw
    [rotary.py, switch.py, userInterface.py]
2020-12-21 userInterface fixed.
    main issue was hw error
    [rotary.py, userInterface.py]
2020-12-28 Stepper implementation working. Basic SMBUS implementation working.
2020-12-28 stepper property access through smbus working
2020-12-28 ADc code fixed. Sensing now does not hang with i2c activity.
    [main.cpp, smbusMsp430.py]
2020-12-31 Control of device improved. rotaries can change media source and item.
2021-01-04 Hall detection modified to detect trend change instead of absolute threshold
2021-01-05 spotypy handling improved. i2c handling improved. i2s-pipe initiation included.
2021-01-05 spotify local device check added in all operations
2021-01-05 Independent debounce times defined and added to SMBUS Stepper stops during debounce.
2021-01-05 Weather Station reactivated. WW flaps working correctly.
    [simpleSgp30.py, splitFlapThread.py]
2021-01-13 Code refactoring. * Location working * Sensors working * Weather working * Historic working
2021-01-15 Clock calibration working.
2021-01-15 sensor io event renamed.
2021-01-15 Raspotify service restart included when device not found
2021-02-09 stencil reference inserted
2021-02-09 3d files added
    [Frontal.stl, axle.stl, cover.stl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]
